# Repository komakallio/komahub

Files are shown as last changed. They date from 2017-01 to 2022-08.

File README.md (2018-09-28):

KomaHub Remote Power Switch and Sensor Platform
===============================================

Contents
--------

**EDA** - schematics and board layout, made in Eagle

**case** - STL files for a 3D-printed case

**software** - KomaHub control software

**firmware** - Firmware code

**tools** - tools for operating the KomaHub

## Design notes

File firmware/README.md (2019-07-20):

# KomaHub firmware

## Compiling the firmware

In order for the firmware to use a custom USB Product ID, the usb_rawhid core must be manually modified as there
is no way to do this from Arduino/PlatformIO code.

`~/.platformio/packages/framework-arduinoteensy/cores/usb_rawhid/usb_private.h`:

```
#define VENDOR_ID               0x1209
#define PRODUCT_ID              0x4242
```

```
#ifndef STR_PRODUCT
#define STR_PRODUCT             L"KomaHub Remote Power Switch"
#endif
#ifndef STR_RAWHID
#define STR_RAWHID              L"KomaHub Remote Power Switch"
#endif
```

Also add the following definition to let firmware code know that the core has been modified:

`~/.platformio/packages/framework-arduinoteensy/cores/usb_rawhid/core_id.h`:

```
#define CORE_KOMAHUB_OK
```

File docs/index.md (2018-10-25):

KomaHub is an intelligent power and sensor hub designed for astronomical applications. It’s particularly useful for running a remote control astrophotography setup. Typical use cases are:

- Troubleshoot a stuck device by power cycling
- Turn off a camera with no software fan control for daytime, for saving the fan
- Keep equipment powered on for preventing condensation
- Automatic dew heater control, following temperature and dewpoint
- Collect sensor data of sky quality during exposures

Manual available [in Finnish](manual-finnish.html)

Download control software from the [releases page](https://github.com/komakallio/komahub/releases).

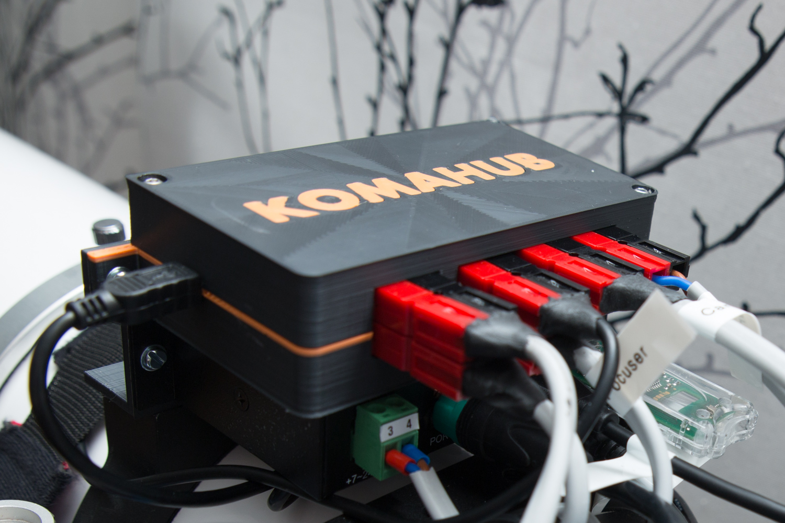
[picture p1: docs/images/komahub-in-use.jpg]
KomaHub in use


**Main features**:
- Six (6) intelligent switchable 12 V outputs
  - Maximum current 8 A per port, 15 A total
  - Chip level protection for overload, overtemperature, polarity and short circuit
  - Continuous current measurement on each port
  - Fast tripping soft fuse with user-definable current limit
- One always-on 12 V output, 15 A maximum
- Any output can use PWM to control dew heaters
  - Slow PWM frequency to prevent RF interference with camera
  - Outputs 1 and 2 can also use fast (xx khz) PWM for e.g. controlling fans (external filtering circuit may be required)
- Input voltage monitoring
- High-quality Anderson Powerpole connectors
- RJ45 port and two 3.5 mm stereo jacks for external sensors
  - Temperature + humidity + pressure sensor
  - 1-wire temperature sensors
  - Cloud sensor
  - Sky quality (darkness) sensor
- Atmel ATmega32U4 microcontroller
- Computer connection with USB HID - no need for serial port drivers
- Control software for Windows
- ASCOM ObservingConditions driver
- ASCOM SafetyMonitor driver for a clean shutdown if running on batteries
- Open firmware, communication protocol, drivers and software

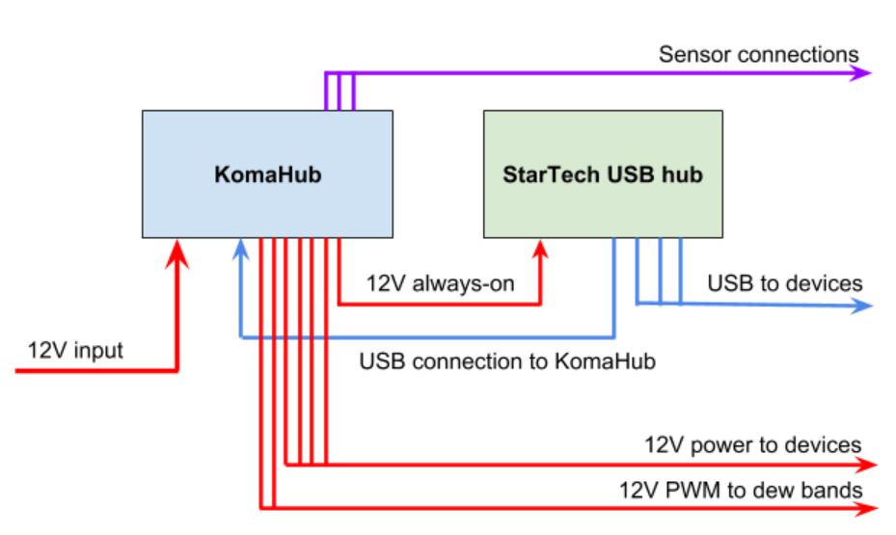
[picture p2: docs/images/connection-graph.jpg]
KomaHub connectivity


The KomaHub is designed to be used with StarTech industrial USB hubs that accept 12V input voltage and have proven to be very reliable. This way the always-on power output can be connected to the hub, making KomaHub always available to the computer. You can also chain KomaHubs together via the always-on port, but the total current level may not exceed 15 amperes.

## Power Switching

The main KomaHub feature is six computer-controlled 12V ports capable of delivering up to 8 A per channel or 15 A in total. The switching is implemented with latest Infineon PROFET switches, designed for rough environments such as automotive use. They feature the latest protection technologies along with high throughput and real-time current measurement.

The power to each port can be toggled from the provided control software. Each port provides either steady DC for your devices or PWM-modulated power for dew heaters. The rate of the PWM is deliberately kept very slow, in order to not disturb sensitive devices such as imaging cameras.

Each port has a software fuse with user-definable current limits. They are much faster than regular fuses and resettable from the control software. Ideal for remote use!

The 12V input voltage of the system is constantly monitored. An user-definable low voltage limit may be specified for shutting down power ports if your input voltage drops due to e.g. a low battery. The low voltage condition can be communicated to your imaging software via an ASCOM SafetyMonitor driver for a controlled shutdown.

## External Sensors

KomaHub can be used for collecting data of external sensors. There are three external connectors.

- The RJ45 connector houses ground and 5 volt lines, I2C bus lines (SCL, SDA) and SPI bus lines (MOSI, MISO, CLK, CS). 
- Usable I2C sensors include
  - *BME280 temperature/humidity/pressure sensor* - Measures ambient conditions for ASCOM or for automatic control of dew heaters
  - *MLX90614 infrared temperature sensor* - Measures sky temperature for sensing cloudiness. Narrow field of view version of the sensor can be aligned with th telescope.

One 3.5 mm stereo jack can be used for a chain of 1-wire temperature sensors (DS18B20), sensing dew heater temperature for automatic control.

The second 3.5 mm jack is used for sensing night sky quality with the TSL237 light-to-frequency sensor, same one as used in Unihedron Sky Quality Meter.

All sensor data can be relayed to the ASCOM ObservingConditions driver and be written in, e.g., the FITS header metadata.

The I2C and 1-wire lines have on-board pullup resistors which can be disabled using jumpers, if using sensor breakout boards with pullups installed.

The KomaHub firmware and software is open source for enabling the use of other sensors. Custom firmware also enables to use any of the available 8 data lines as general purpose I/O for other applications.

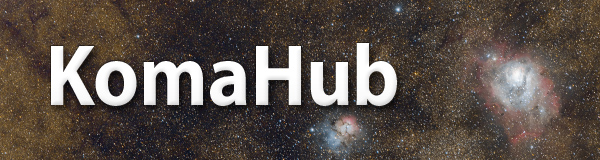
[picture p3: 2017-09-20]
software/KomaHub/KomaHub/Resources/komahub.jpg

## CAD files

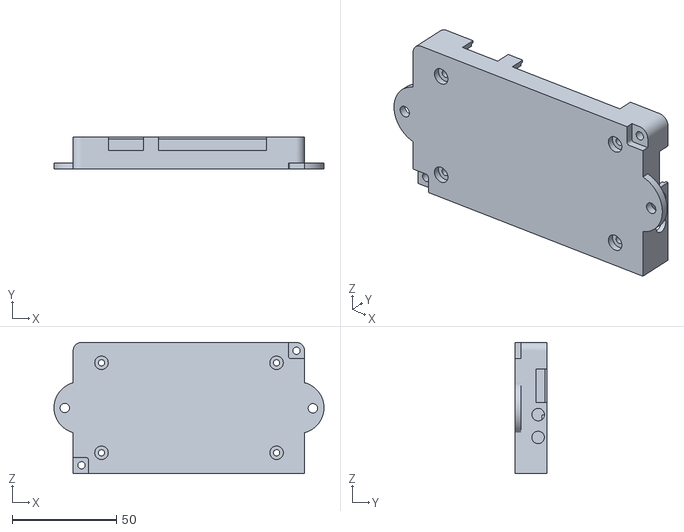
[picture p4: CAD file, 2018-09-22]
case/Komahub-1.2-BODY.stl
129.6 x 15.5 x 63.0

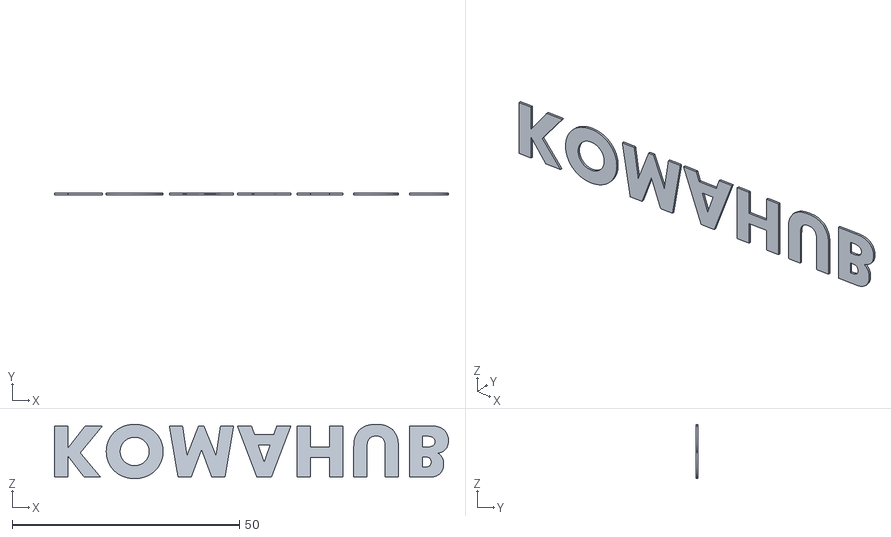
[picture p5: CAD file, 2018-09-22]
case/Komahub-1.2-LOGO.stl
86.7 x 0.45 x 11.9

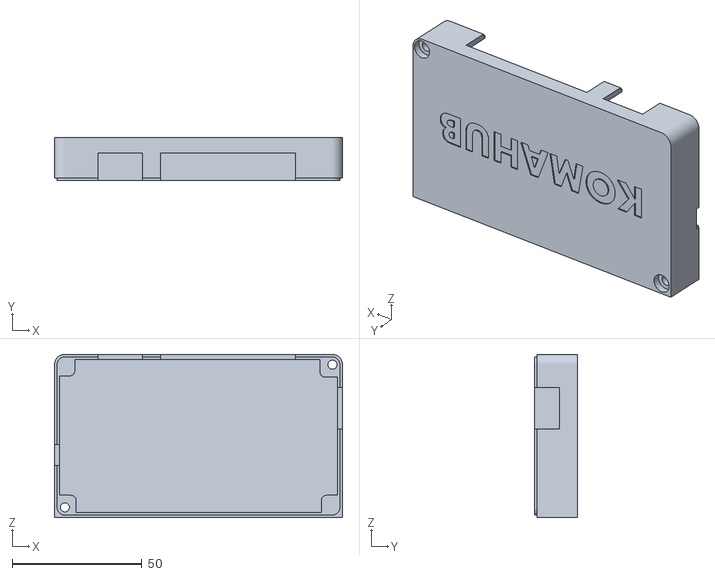
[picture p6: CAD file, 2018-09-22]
case/Komahub-1.2-LID.stl
111.0 x 16.5 x 63.0

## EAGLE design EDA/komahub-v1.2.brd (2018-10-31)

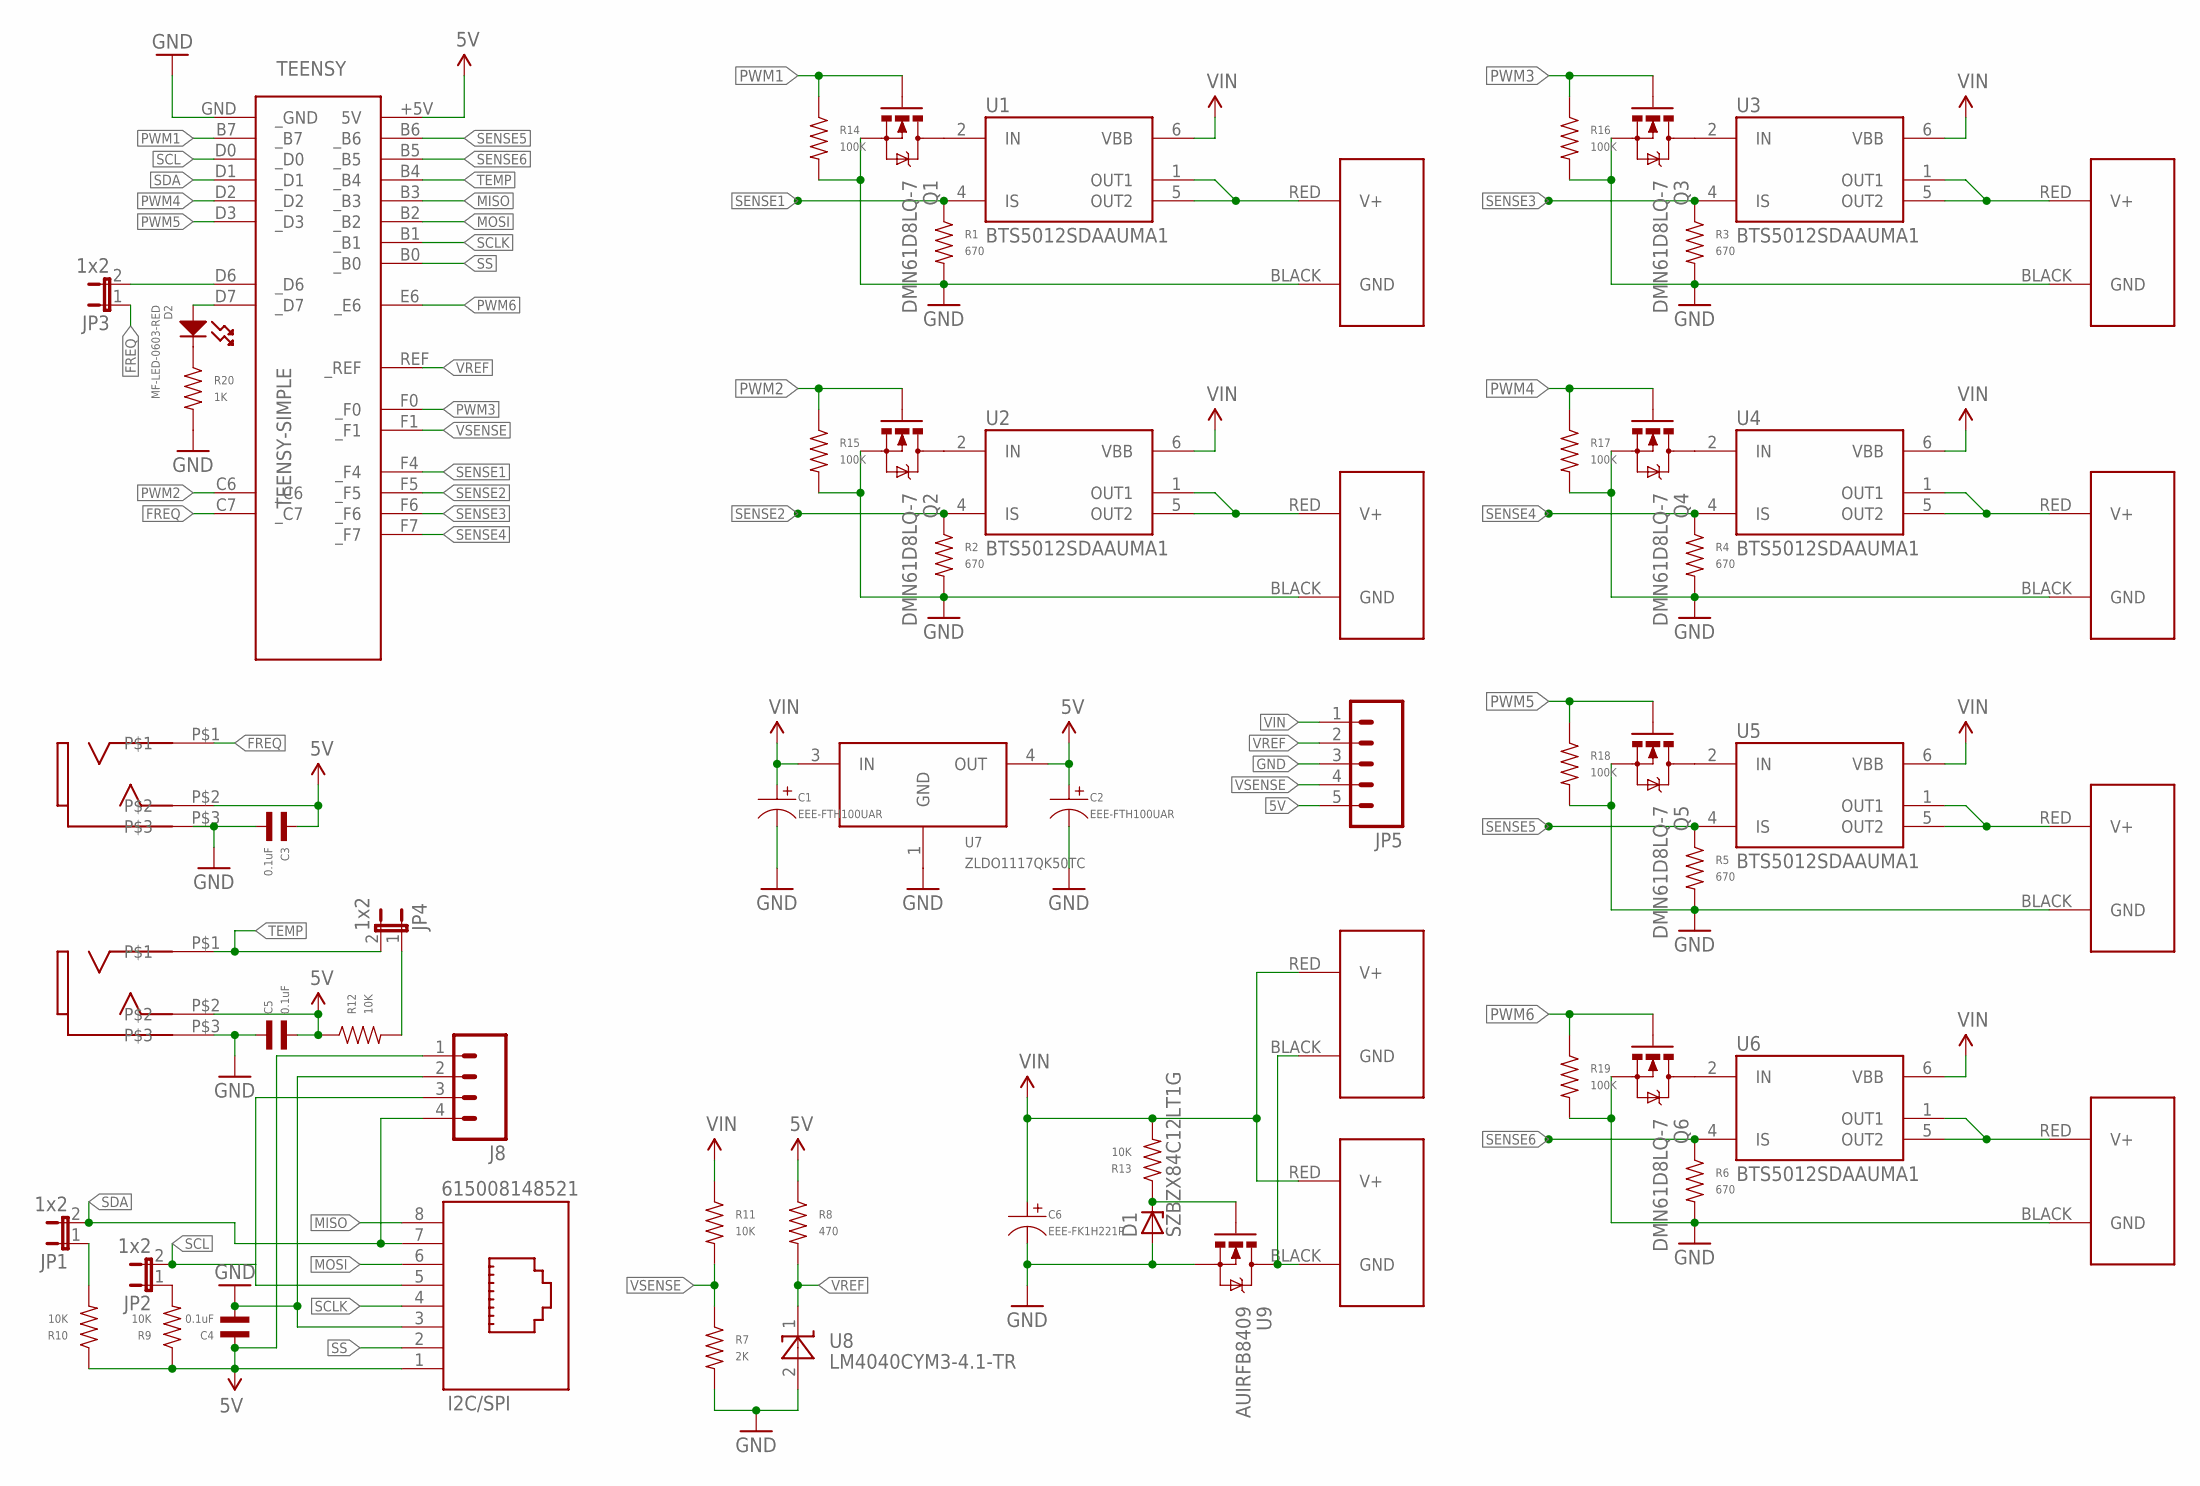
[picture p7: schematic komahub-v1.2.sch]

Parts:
C1, C2: EEE-FTH100UAR; CP4MM; MPN MF-CAP-4MM-10uF
C3, C4, C5: 0.1uF; C0603
C6: EEE-FK1H221P; CP10MM; MPN EEE-FT1H221AP
D1: SZBZX84C12LT1G; SOT23
D2: MF-LED-0603-RED; LED0603
FREQ: 35RASMT2BHNTRX
I2C/SPI: 615008148521
J1, J2, J6, J7: POWERPOLE_POWER25A_HORIZONTAL_G11; POWERPOLE_PAIR_25A_HORIZ_G11
J3, J4, J5, J9: POWERPOLE_POWER25A_HORIZONTAL_G12; POWERPOLE_PAIR_25A_HORIZ_G12
J8: M04PTH; 1X04
JP1, JP2, JP3, JP4: 1x2; 1X02
JP5: M05PTH; 1X05
Q1, Q2, Q3, Q4, Q5, Q6: DMN61D8LQ-7; SOT23-3
R1, R2, R3, R4, R5, R6: 670; R0603; MPN CR0603-FX-6800ELF
R7: 2K; R0603; MPN MF-RES-0603-2K
R8: 470; R0603; MPN MF-RES-0603-470
R9, R10, R11, R12, R13: 10K; R0603; MPN MF-RES-0603-10K
R14, R15, R16, R17, R18, R19: 100K; R0603; MPN MF-RES-0603-2K
R20: 1K; R0603
TEENSY: TEENSY-SIMPLE
TEMP: 35RASMT2BHNTRX
U1, U2, U3, U4, U5, U6: BTS5012SDAAUMA1; TO114P998X235-5_6N
U7: ZLDO1117QK50TC; DPAK
U8: LM4040CYM3-4.1-TR; SOT-23
U9: AUIRFB8409; TO220AV

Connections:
5V: C2.P$1, C3.P$1, C4.P$1, C5.P$2, FREQ.P$2, I2C/SPI.1 (8), J8.1, JP5.5, R8.P$1, R9.P$1, R10.P$1, R12.P$1, TEENSY.+5V (5V), TEMP.P$2, U7.4 (OUT)
FREQ: FREQ.P$1, JP3.1, TEENSY.C7 (_C7)
GND: C1.P$2, C2.P$2, C3.P$2, C4.P$2, C5.P$1, C6.P$2, D1.1 (A), FREQ.P$3, I2C/SPI.3 (6), J1.BLACK (GND), J2.BLACK (GND), J3.BLACK (GND), J5.BLACK (GND), J7.BLACK (GND), J8.2, J9.BLACK (GND), JP5.3, Q1.2 (S), Q2.2 (S), Q3.2 (S), Q4.2 (S), Q5.2 (S), Q6.2 (S), R1.P$2, R2.P$2, R3.P$2, R4.P$2, R5.P$2, R6.P$2, R7.P$2, R14.P$2, R15.P$2, R16.P$2, R17.P$2, R18.P$2, R19.P$2, R20.P$2, TEENSY.GND (_GND), TEMP.P$3, U7.1 (GND), U8.2 (A), U9.3 (S)
GNDIN: J4.BLACK (GND), J6.BLACK (GND), U9.2 (D)
MISO: I2C/SPI.8 (1), TEENSY.B3 (_B3)
MOSI: I2C/SPI.6 (3), TEENSY.B2 (_B2)
unnamed: JP3.2, TEENSY.D6 (_D6)
unnamed: JP2.1, R9.P$2
unnamed: JP4.1, R12.P$2
unnamed: JP1.1, R10.P$2
unnamed: D1.3 (C), R13.P$1, U9.1 (G)
unnamed: D2.CATHODE, R20.P$1
unnamed: D2.ANODE, TEENSY.D7 (_D7)
PWM1: Q1.1 (G), R14.P$1, TEENSY.B7 (_B7)
PWM2: Q2.1 (G), R15.P$1, TEENSY.C6 (_C6)
PWM3: Q3.1 (G), R16.P$1, TEENSY.F0 (_F0)
PWM4: Q4.1 (G), R17.P$1, TEENSY.D2 (_D2)
PWM5: Q5.1 (G), R18.P$1, TEENSY.D3 (_D3)
PWM6: Q6.1 (G), R19.P$1, TEENSY.E6 (_E6)
PWMT1: Q1.3 (D), U1.2 (IN)
PWMT2: Q2.3 (D), U2.2 (IN)
PWMT3: Q3.3 (D), U3.2 (IN)
PWMT4: Q4.3 (D), U4.2 (IN)
PWMT5: Q5.3 (D), U5.2 (IN)
PWMT6: Q6.3 (D), U6.2 (IN)
PWR1: J2.RED (V+), U1.1 (OUT1), U1.5 (OUT2)
PWR2: J3.RED (V+), U2.1 (OUT1), U2.5 (OUT2)
PWR3: J1.RED (V+), U3.1 (OUT1), U3.5 (OUT2)
PWR4: J5.RED (V+), U4.1 (OUT1), U4.5 (OUT2)
PWR5: J7.RED (V+), U5.1 (OUT1), U5.5 (OUT2)
PWR6: J9.RED (V+), U6.1 (OUT1), U6.5 (OUT2)
SCL: I2C/SPI.5 (4), J8.3, JP2.2, TEENSY.D0 (_D0)
SCLK: I2C/SPI.4 (5), TEENSY.B1 (_B1)
SDA: I2C/SPI.7 (2), J8.4, JP1.2, TEENSY.D1 (_D1)
SENSE1: R1.P$1, TEENSY.F4 (_F4), U1.4 (IS)
SENSE2: R2.P$1, TEENSY.F5 (_F5), U2.4 (IS)
SENSE3: R3.P$1, TEENSY.F6 (_F6), U3.4 (IS)
SENSE4: R4.P$1, TEENSY.F7 (_F7), U4.4 (IS)
SENSE5: R5.P$1, TEENSY.B6 (_B6), U5.4 (IS)
SENSE6: R6.P$1, TEENSY.B5 (_B5), U6.4 (IS)
SS: I2C/SPI.2 (7), TEENSY.B0 (_B0)
TEMP: JP4.2, TEENSY.B4 (_B4), TEMP.P$1
VIN: C1.P$1, C6.P$1, J4.RED (V+), J6.RED (V+), JP5.1, R11.P$1, R13.P$2, U1.6 (VBB), U2.6 (VBB), U3.6 (VBB), U4.6 (VBB), U5.6 (VBB), U6.6 (VBB), U7.3 (IN)
VREF: JP5.2, R8.P$2, TEENSY.REF (_REF), U8.1 (C)
VSENSE: JP5.4, R7.P$1, R11.P$2, TEENSY.F1 (_F1)

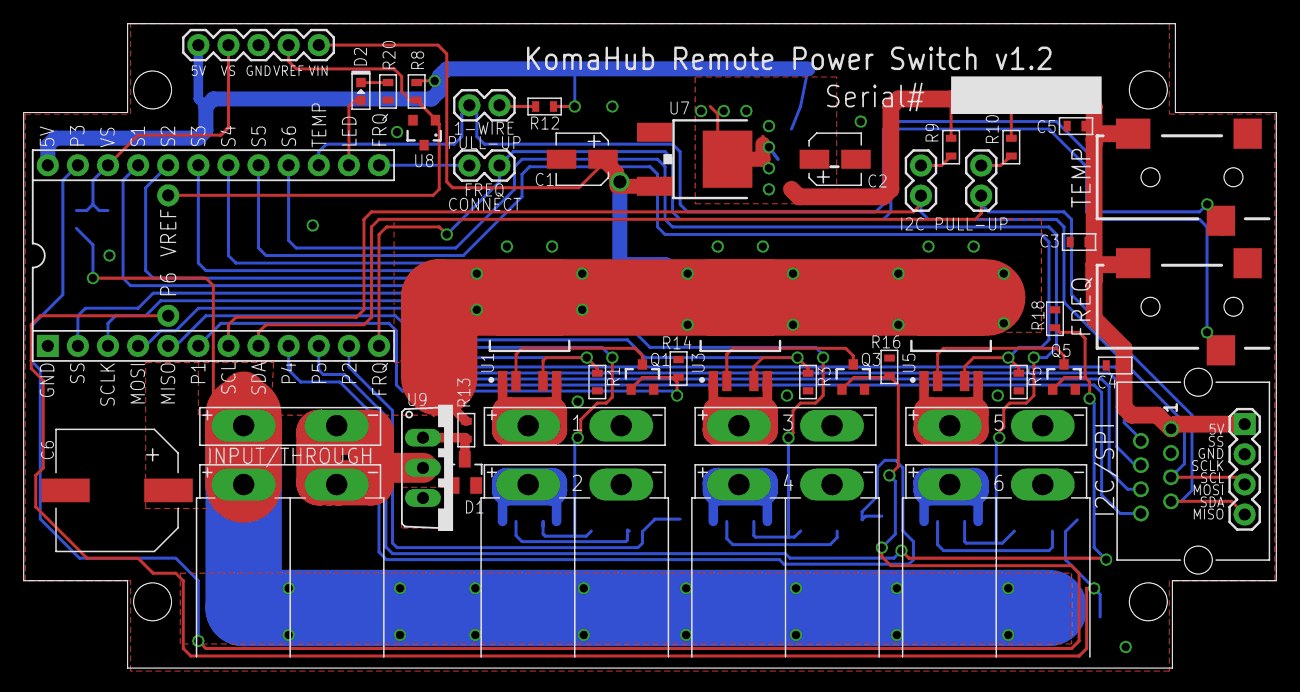
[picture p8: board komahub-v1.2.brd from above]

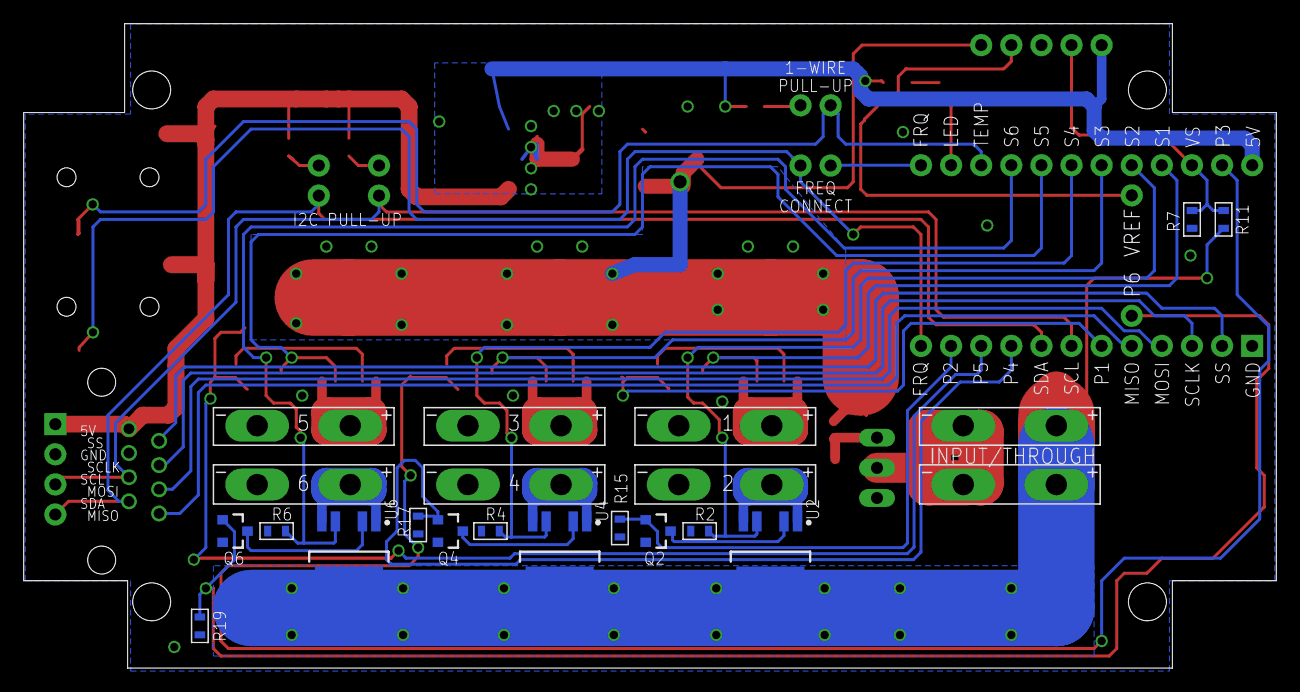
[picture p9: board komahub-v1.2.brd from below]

Board: 2 copper layers, 105.7 x 54.4 mm, 61 parts (14 on the bottom side), 45 nets.

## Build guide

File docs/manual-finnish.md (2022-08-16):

# KomaHub - kotimainen sähkölaatikko tähtikuvaukseen

KomaHub on Komakalliolla kehitetty apulaite tähtikuvaukseen. KomaHubilla korvaat perinteisen rinnankytketyn 12 voltin sähkönjakolaatikon ja saat hienoja lisäominaisuuksia.

Laite on erityisen hyödyllinen etäkäyttöisessä observatoriossa, jossa on tarve käynnistää ja sammuttaa 12 voltilla toimivia laitteita etänä ja tarkkailla niiden virrankulutusta. Lisäksi KomaHubiin on mahdollista kytkeä useita erilaisia antureita, joiden avulla voi tarkkailla kuvausolosuhteita ja tallentaa tämän tiedon suoraan raakakuvien metadataksi.

Tyypillisiä käyttökohteita ovat esimerkiksi:
- Temppuilevan laitteen korjaaminen katkaisemalla virrat
- CCD-kameran sammuttaminen päiväsajaksi, jos kameran tuuletin muuten pyörisi aina kun virta on kytkettynä
- Laitteiden pitäminen virroissa tiivistyvän kosteuden välttämiseksi
- Huurrepantojen automaattinen säätö kuvauksen aikana
- Taivaan pimeyden ja muiden suureiden mittaaminen kuvatessa

Ominaisuudet:
- Kuusi yksittäin tietokoneella ohjattavaa virtaulostuloa
  - Maksimi 8 A per portti, yhteensä 15 A
  - Jatkuva virtamittaus per portti
  - Ohjelmallisesti toteutettu nopea sulake käyttäjän valitsemalla virtarajoituksella
- Yksi jatkuvasti päällä oleva virtaulostulo (kytketty rinnan sisääntulon kanssa)
- Jokaiseen kuudesta ulostulosta voi määrittää PWM:n esim. huurrepannan ohjaamista varten
- Sisääntulojännitteen mittaus
- Laadukkaat Powerpole-liittimet
- Mahdollisuus kytkeä ulkoisia antureita (lämpötila, paine, kosteus, pilvisyys, taustataivaan kirkkaus)
- Atmel ATmega32U4 mikrokontrolleri
- Toimii USB HID-laitteena - ei sarjaporttiajureiden asentelua!
- Ohjausohjelma Windowsille
- ASCOM-ajurit ObservingConditions ja SafetyMonitor -rajapinnoille
- Kaikki lähdekoodi (firmware, protokollat, ajurit ja ohjelmisto) ja piirilevysuunnittelu on avoimesti jaossa

## Kytkennät

KomaHub kytketään tietokoneeseen Mini-USB-liittimellä. Lisäksi laitteelle syötetään 12 voltin käyttöjännite alla olevaan kuvaan merkityn Powerpole-liittimen kautta (**12V input**). Syöttöjännitteelle tarkoitetun liittimen alapuolella on toinen Powerpole-liitin, joka on kytketty rinnakkain syöttöjännitteen kanssa. Tästä liittimestä voi jakaa 12 V sähkön laitteille, joiden haluat aina olevan päällä, esim. USB-hubi, johon KomaHub on kytketty.

12 V syötön tulee olla aina kytkettynä. KomaHub osaa toimia itsenäisesti ilman tietokonetta pitäen voimassa sille määritellyt asetukset, joten se ei ota sähköä USB:n kautta eikä näin toimi ilman sähkönsyöttöä.

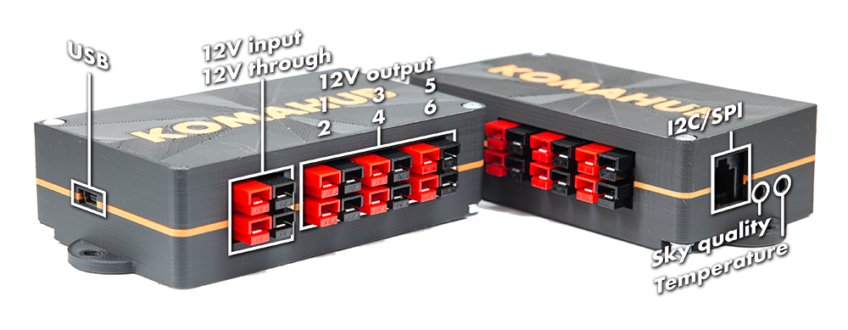
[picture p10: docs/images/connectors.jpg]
Liittimet


Kuvaan merkityt **12V output** -liittimet ovat KomaHubilla ohjattavia laitteita varten. Liittimet on numeroitu kuvassa näkyvässä järjestyksessä.

Lisäksi laitteen kyljessä ovat RJ45- ja 3,5 mm stereoliittimet erilaisia oheisantureita varten. Reunimmainen 3,5mm liitin on lämpötilasensoreita varten (**Temperature**), keskimmäinen 3,5mm liitin TSL237-valoisuusanturia varten (**Sky quality**) ja RJ45-liitin I2C/SPI -väyliin liitettäviä antureita varten (**I2C/SPI**), esim. lämpötila/ilmanpaine/kosteus (BME280) tai pilvisensori (MLX90614). Kun anturit eivät ole käytössä, voi kotelon kyljen teipata umpeen, jotta sisälle ei mene ulkokäytössä kosteutta tai ötököitä.

## Windows-ohjelman käyttö

KomaHubia ohjataan Windows-työpöytäohjelmalla, jonka käyttöliittymästä näet kuvakaappauksen alla. **Power Outputs** -otsikon alta näet listauksen kaikista kuudesta virtalähdöstä sekä niiden tilasta. Jokaiselle lähdölle voi antaa nimen, joka vastaa lähtöön kytkettyä laitetta. Käyttöliittymä näyttää myös jokaisen lähdön virrankulutuksen, sekä antaa mahdollisuuden kytkeä kukin lähtö päälle tai pois klikkaamalla **On/Off**-nappia.

Jos lähdön tyypiksi on asetuksissa valittu PWM, näkyy lähdölle myös käyttöjakson säätö (0-100%). Tällä voi esimerkiksi lämmityspantojen tapauksessa säätää lämmitystehoa.

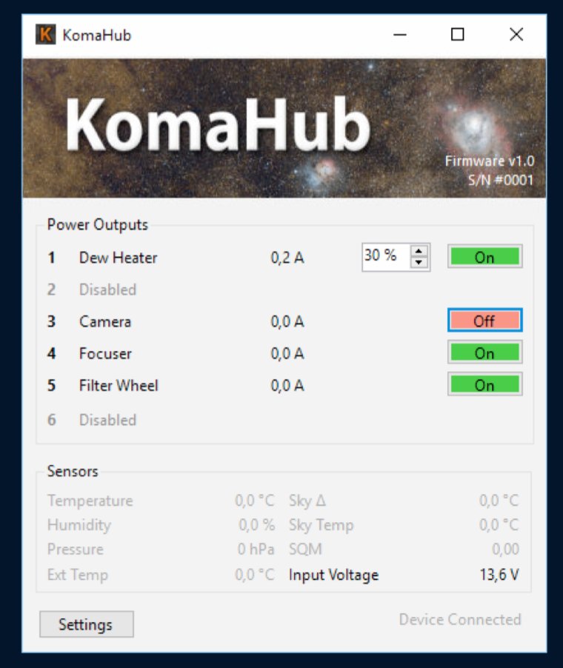
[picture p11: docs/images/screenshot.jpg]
KomaHub-kuvakaappaus


**Sensors**-otsikon alta näet kaikkien KomaHubiin kytkettyjen anturien tilan. Listan lopusta löytyy myös mitattu syöttöjännite. Syötetyn jännitteen tulisi olla välillä 12-14 V.

**Settings**-nappia painamalla voit säätää KomaHubin käyttämiä asetuksia. Jokaiselle lähdölle voi valita nimen, tyypin sekä sulakkeen käyttämän virtarajan.

Lähtöjen tyypit ovat seuraavanlaiset:
- **12V** - Lähtö on normaalisti käytössä ja antaa 12 voltin jännitettä
- **PWM** - Lähtö antaa säädettävää PWM-jännitettä, jolla voi ohjata esimerkiksi lämmityspantoja
- **OFF** - Lähdön käyttö on kokonaan estetty ja näkyy käyttöliittymässä *Disabled*-tilassa

## Linux-tuki

Jarno Paananen on tehnyt KomaHubille INDI-ajurin, joka löytyy osoitteesta https://github.com/jpaana/indi-komahub.

## Sensorikytkennät

KomaHubiin voidaan liittää monenlaisia sensoreita. Laite havaitsee kytketyt sensorit kun siihen kytketään virta, ja välittää niillä mitatut tiedot tietokoneelle, jossa niitä voi seurata KomaHubin ohjaussovelluksella.

**Huom!** Älä kytke tai irroita sensoreita kun KomaHubissa on virrat!

### One-wire lämpötila-anturit

KomaHubiin voidaan kytkeä ketjuun 1-4kpl DS18B20 lämpötila-anturia. Anturit johdotetaan 3,5mm TRS-stereoplugiin seuraavasti:

- Tip = +5V
- Ring = Data
- Sleeve = GND

Lisäksi tarvitaan ylösvetovastus Data- ja +5V-linjojen väliin. Jos anturisi yhteydessä ei sellaista ole, voi KomaHubin sisäänrakennetun vastuksen kytkeä käyttöön sulkemalla piirilevyltä jumpperi `1-WIRE PULL-UP`.

KomaHub tunnistaa antureiden lukumäärän käynnistyessään. Mittaus tehdään neljälle anturille, joista KomaHubin ohjaussovellus näyttää kaksi ensimmäistä.

### TSL237 valoisuusanturi

TSL237-valoisuusanturilla voidaan mitata taivaan kirkkautta. Lopputuloksena saadaan vastaava magnitudia/neliökaarisekunti-tulos kuin Unihedronin valmistamilla SQM-mittareilla. Vertailukelpoisen tuloksen saamiseksi anturi tarvitsee eteensä IR:n ja UV:n leikkaavan suodattimen (Unihedronin laitteessa HOYA CM-500) sekä linssin jolla mittaukseen haluttu kuvakenttä kohdistetaan anturiin.

Itse anturi muuttaa kirkkauden taajuuspulssiksi jota KomaHubin mikrokontrolleri lukee. Taajuus `f` muunnetaan mag/arcsec^2 -lukemaksi kaavalla `22 - 2.5 * log10(f)`. Mitattu taajuuslukema on myös saatavilla omia laskelmia varten ohjaussovelluksessa tooltippinä osoittamalla hiirellä Sky Quality -lukemaa. Koska anturilta saatavan taajuuden vaihteluväli on erittäin suuri (n. 0,1Hz - 500kHz), käyttää KomaHub sen seuraamiseen kahta eri mekanismia jotta saadaan paras tarkkuus mahdollisimman vähällä CPU-kuormalla. Anturin ollessa käytössä on piirilevyltä suljettava `FREQ CONNECT` -jumpperi, jotta signaali saadaan jaettua mikrokontrollerille kahteen eri pinniin eri lukumekanismien mahdollistamiseksi.

Laite johdotetaan 3,5mm TRS-stereoplugiin seuraavasti:

- Tip = Vdd (2)
- Ring = OUT (3)
- Sleeve = GND (1)

Lisäksi laitteen lähelle Vdd ja GND -linjojen väliin tulee liittää 0.1uF kondensaattori.

**Huom!** Valoisuusanturin tuloksia ei ole vielä päästy vertaamaan ja kalibroimaan oikean SQM-mittarin kanssa. Käyttäjäkokemuksia otetaan vastaan!

### BME280 lämpötila/ilmanpaine/kosteus

BME280 on Boschin valmistama edullinen yhdistelmäanturi, josta saadaan kerralla paikallinen lämpötila, ilmanpaine, kosteus ja näistä edelleen laskettua kastepiste. Anturia saa valmiina I2C breakout-lautana, joka johdotetaan KomaHubin RJ45-liittimeen seuraavasti:

- 1 = +5V
- 3 = GND
- 5 = SCL
- 7 = SDA

Valmiissa breakout-laudoissa on yleensä I2C-väylän tarvitsemat ylösvetovastukset valmiina. Omia rakennelmia tai laitteiden ketjuttamista varten KomaHubissa on myös omat ylösvetovastukset jotka saa käyttöön sulkemalla KomaHubin piirilevyltä kaksi `I2C PULL-UP` -jumpperia.

### MLX90614-sensori pilvisyyden mittaamiseen

MLX90614 on komponentti, joka mittaa kohteesta saapuvan lämpösäteilyn määrää.  Lisäksi siinä on oma lämpötilamittarinsa paikallista referenssilämpötilaa varten. Tällä yhdistelmällä voidaan mitata taivaan pilvisyyttä mittaamalla taivaan ja ilman lämpötilan erotusta. Selkeä taivas on kylmempi kuin pilvinen, joten erotuksen ollessa suuri on keli todennäköisesti selkeä.

Laitetta saa valmiina breakout-lautana, joka liitetään I2C-väylään samalla tavalla kuin BME280:

- 1 = +5V
- 3 = GND
- 5 = SCL
- 7 = SDA

Lisäksi KomaHubin piirilevyltä on suljettava `I2C PULL-UP` -jumpperit, jos sensorin yhteydessä ei ole omia ylösvetovastuksia.

### Muut sensorit

RJ45-liittimeen voidaan kytkeä myös muita I2C- tai SPI-väyliin liitettäviä laitteita. Näille täytyy kuitenkin toteuttaa tuki KomaHubin firmwareen tapauskohtaisesti. Liittimen kytkennät ovat:

- 1 = +5V
- 2 = SS
- 3 = GND
- 4 = SCLK
- 5 = SCL
- 6 = MOSI
- 7 = SDA
- 8 = MISO

## Komentoriviohjaus

KomaHubin Windows-sovelluksessa on REST-verkkorajapinta, jolla laitetta on mahdollista ohjata omista sovelluksista käsin. KomaHubin ASCOM-ajurit käyttävät myös näitä rajapintoja. Komentorivillä näitä voidaan ohjata esim. `curl`-työkalulla.

### Lähtöjen kytkentä päälle/pois

`curl -X POST -d '' http://localhost:6563/output/1/on`  
`curl -X POST -d '' http://localhost:6563/output/1/off`

jossa `output` on lähdön numero 1-6.

### Sensorien lukeminen

`curl http://localhost:6563/sensors`

Tämä kutsu tuottaa seuraavanlaisen JSON-dokumentin joka sisältää sensoreilta viimeksi luetut arvot. Jos vastaavaa sensoria ei ole kytketty, kyseinen osio tai lukema jää vastauksesta kokonaan pois. `power`-osio on kuitenkin aina mukana, sillä se on KomaHubiin sisäänrakennettuna.
```
{
  "pth" : { "temperature": 3.5, "humidity": 70.5, "pressure": 1001.5, "dewpoint": -3.2 },
  "skyquality" : { "magnitude": 21.3, "frequency": 1005 },
  "skytemperature" : { "sky": -15.3, "ambient": 0.2 },
  "power" : { "inputvoltage": 12.5, "outputcurrent": [ 0.0, 0.0, 0.0, 0.0, 0.0, 0.0 ] },
  "temperatures": [ 10.5, 9.5 ]
}
```

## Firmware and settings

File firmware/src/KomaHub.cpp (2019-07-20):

/*
 * Copyright (c) 2016 Jari Saukkonen
 *
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
 * THE SOFTWARE IS PROVIDED "AS IS", WITHOUT WARRANTY OF ANY KIND,
 * EXPRESS OR IMPLIED, INCLUDING BUT NOT LIMITED TO THE WARRANTIES OF
 * MERCHANTABILITY, FITNESS FOR A PARTICULAR PURPOSE AND NONINFRINGEMENT.
 * IN NO EVENT SHALL THE AUTHORS OR COPYRIGHT HOLDERS BE LIABLE FOR ANY
 * CLAIM, DAMAGES OR OTHER LIABILITY, WHETHER IN AN ACTION OF CONTRACT,
 * TORT OR OTHERWISE, ARISING FROM, OUT OF OR IN CONNECTION WITH THE
 * SOFTWARE OR THE USE OR OTHER DEALINGS IN THE SOFTWARE.
 */

#include <Arduino.h>
#include <TaskScheduler.h>
#ifdef CORE_TEENSY_SERIAL
#include <EEPROM.h>
#elif defined(CORE_TEENSY_RAWHID) && !defined(CORE_KOMAHUB_OK)
#error "KomaHub custom core (with proper USB vendor/product ids) not found!"
#elif !defined(CORE_TEENSY_RAWHID)
#error "Teensy core (serial/raw hid) not selected!"
#endif

#include "AnalogInput.h"
#include "HubConfiguration.h"
#include "PowerOutputs.h"
#include "SkyQuality.h"
#include "SkyTemperature.h"
#include "TemperatureSensors.h"
#include "USB.h"
#include "Weather.h"
#include "VersionSpecifics.h"
#include "VoltageMonitor.h"

static Scheduler taskScheduler;
static HubConfiguration configuration;
#ifdef CORE_TEENSY_RAWHID
static Task usbTask(10, TASK_FOREVER, &USB::loop);
#endif
static Task skyQualityTask(50, TASK_FOREVER, &SkyQuality::loop);
static Task skyTemperatureTask(1000, TASK_FOREVER, &SkyTemperature::loop);
static Task analogInputTask(10, TASK_FOREVER, &AnalogInput::loop);
static Task powerOutputsTask(5, TASK_FOREVER, &PowerOutputs::loop);
static Task temperatureSensorsTask(2000, TASK_FOREVER, &TemperatureSensors::loop);
static Task weatherTask(2000, TASK_FOREVER, &Weather::loop);
static Task voltageMonitorTask(10, TASK_FOREVER, &VoltageMonitor::loop);

void setup() {
    configuration.loadStoredConfiguration();
    VersionSpecifics::setBoardRevision(configuration.getFactoryConfig().boardRevision);

    taskScheduler.init();
#ifdef CORE_TEENSY_RAWHID
    USB::init(&configuration);
    taskScheduler.addTask(usbTask);
#endif

    AnalogInput::init(&configuration);
    taskScheduler.addTask(analogInputTask);

    PowerOutputs::init(&configuration);
    taskScheduler.addTask(powerOutputsTask);

    VoltageMonitor::init(&configuration);
    taskScheduler.addTask(voltageMonitorTask);

    SkyQuality::init(&configuration);
    taskScheduler.addTask(skyQualityTask);

    SkyTemperature::init(&configuration);
    taskScheduler.addTask(skyTemperatureTask);

    TemperatureSensors::init(&configuration);
    taskScheduler.addTask(temperatureSensorsTask);

    Weather::init(&configuration);
    taskScheduler.addTask(weatherTask);

    taskScheduler.enableAll();
}

void loop() {
    taskScheduler.execute();
#ifdef CORE_TEENSY_SERIAL
    if (Serial.available()) {
        char ch = Serial.read();
        if (ch == 'd') {
            Serial.print("eeprom dump: ");
            for (int i = 0; i < 1024; i++) {
                if (i % 32 == 0) Serial.println();
                Serial.print(EEPROM.read(i), HEX);
                Serial.print(" ");
            };
            Serial.println();
        }
        if (ch == 'f') {
            configuration.factoryReset(1, 6, 12000, 2000, 255, 220, 15);
            Serial.println("factory was reset");
        }
    }
#endif
}

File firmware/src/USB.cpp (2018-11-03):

/*
 * Copyright (c) 2016 Jari Saukkonen
 *
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
 * THE SOFTWARE IS PROVIDED "AS IS", WITHOUT WARRANTY OF ANY KIND,
 * EXPRESS OR IMPLIED, INCLUDING BUT NOT LIMITED TO THE WARRANTIES OF
 * MERCHANTABILITY, FITNESS FOR A PARTICULAR PURPOSE AND NONINFRINGEMENT.
 * IN NO EVENT SHALL THE AUTHORS OR COPYRIGHT HOLDERS BE LIABLE FOR ANY
 * CLAIM, DAMAGES OR OTHER LIABILITY, WHETHER IN AN ACTION OF CONTRACT,
 * TORT OR OTHERWISE, ARISING FROM, OUT OF OR IN CONNECTION WITH THE
 * SOFTWARE OR THE USE OR OTHER DEALINGS IN THE SOFTWARE.
 */

#include <Arduino.h>

#ifdef CORE_TEENSY_RAWHID

#include "AnalogInput.h"
#include "HubConfiguration.h"
#include "PowerOutputs.h"
#include "SkyQuality.h"
#include "SkyTemperature.h"
#include "TemperatureSensors.h"
#include "USB.h"
#include "USBCommands.h"
#include "Weather.h"
#include "Version.h"
#include "VoltageMonitor.h"

static uint8_t usbSendBuffer[64];
static uint8_t usbRecvBuffer[64];

HubConfiguration* USB::hubConfiguration;

void USB::loop() {
    int available = RawHID.available();
    if (available > 0) {
        memset(usbSendBuffer, 0, 64);
        RawHID.recv(usbRecvBuffer, available);
        handleCommands(usbRecvBuffer, available);
    }
}

void USB::handleCommands(uint8_t* data, unsigned int maxlen) {
    unsigned int pos = 0;
    if (data[pos++] != 'K')
        return;

    while (pos < maxlen) {
        uint8_t command = data[pos++];
        switch (command) {
            case END: {
                return;
            }

            case GETFACTORYSETTINGS: {
                const HubConfiguration::FactoryConfig& factoryConfig = hubConfiguration->getFactoryConfig();
                GetFactorySettingsResponse response;

                response.firmwareVersion = (KOMAHUB_FIRMWARE_VERSION_MAJOR << 8) + KOMAHUB_FIRMWARE_VERSION_MINOR;
                response.serialNumber = factoryConfig.serial;
                response.fuseDelay = factoryConfig.fuseDelay;
                response.skyQualityOffset = factoryConfig.skyQualityOffset;
                response.features = (uint8_t)(
                    (factoryConfig.features.tempprobes ? (1 << 0) : 0) +
                    (factoryConfig.features.skyquality ? (1 << 1) : 0) +
                    (factoryConfig.features.ambientpth ? (1 << 2) : 0) +
                    (factoryConfig.features.skytemp ? (1 << 3) : 0));
                response.boardRevision = factoryConfig.boardRevision;

                memcpy(usbSendBuffer, &response, sizeof(GetFactorySettingsResponse));
                RawHID.send(usbSendBuffer, 1000);
                break;
            }

            case GETOUTPUTSETTINGS: {
                GetOutputSettingsCommand* cmd = (GetOutputSettingsCommand*)&data[pos];
                if (!isValidOutput(cmd->outputNumber))
                    break;
                GetOutputSettingsResponse response;

                const HubConfiguration::OutputSettings& outputSettings = hubConfiguration->getOutputSettings();
                const HubConfiguration::Output& output = outputSettings.outputs[cmd->outputNumber];
                memcpy(&response.name, output.name, 16);
                response.fuseCurrent = output.fuseCurrent;
                response.type = output.type.type;

                memcpy(usbSendBuffer, &response, sizeof(GetOutputSettingsResponse));
                RawHID.send(usbSendBuffer, 1000);
                pos += sizeof(GetOutputSettingsCommand);
                break;
            }

            case GETSTATUS: {
                GetStatusResponse response;

                const HubConfiguration::State& state = hubConfiguration->getState();
                response.relayIsOpenBits = state.relayIsOpenBits;
                response.fuseIsBlownBits = state.fuseIsBlownBits;
                for (int i = 0; i < 6; i++) {
                    response.pwmPercentages[i] = state.pwmPercentages[i];
                }
                // input voltage
                response.inputVoltage = (uint8_t)roundf(VoltageMonitor::getInputVoltage() * 10);
                // output power, amps
                for (int i = 0; i < 6; i++) {
                    response.outputPower[i] = (uint8_t)roundf(PowerOutputs::getOutputPower(i) * 10);
                }
                // 1-wire temperature probes
                response.numberOfTemperatureProbes = TemperatureSensors::getNumberOfSensors();
                for (int i = 0; i < 4; i++) {
                    response.temperatureProbes[i] = TemperatureSensors::getCurrentTemperatureValues()[i] * 10;
                }
                // weather
                response.pthpresent = Weather::isSensorPresent();
                response.temperature = Weather::getTemperature() * 10;
                response.humidity = Weather::getHumidity();
                response.pressure = Weather::getPressure() * 10;
                response.dewpoint = Weather::getDewPoint() * 10;
                // sky quality
                response.skyqualitypresent = SkyQuality::isSensorPresent();
                response.skyquality = SkyQuality::getSkyQuality() * 10;
                response.skyqualityfreq = SkyQuality::getFrequencyHz() * 10;
                // sky temperature
                response.skytemperaturepresent = SkyTemperature::isSensorPresent();
                response.skytemperature = SkyTemperature::getSkyTemperature() * 10;
                response.skyambienttemperature = SkyTemperature::getAmbientTemperature() * 10;

                memcpy(usbSendBuffer, &response, sizeof(GetStatusResponse));
                RawHID.send(usbSendBuffer, 1000);
                break;
            }

            case GETRAWPOWERUSAGE: {
                GetRawPowerUsageResponse response;
                memcpy(&response.rawValues, AnalogInput::getAverageValues(), 8*sizeof(uint16_t));
                memcpy(usbSendBuffer, &response, sizeof(GetRawPowerUsageResponse));
                RawHID.send(usbSendBuffer, 1000);
                break;
            }

            case FACTORYRESET: {
                FactoryResetCommand* cmd = (FactoryResetCommand*)&data[pos];
                USB::hubConfiguration->factoryReset(cmd->serial, cmd->r6ohms, cmd->r7ohms, cmd->boardRevision);
                pos += sizeof(FactoryResetCommand);
                break;
            }

            case REBOOT_BOOTLOADER: {
                cli();
                // disable watchdog, if enabled
                // disable all peripherals
                UDCON = 1;
                UCSR1B = 0;
                delay(5);
                EIMSK = 0; PCICR = 0; SPCR = 0; ACSR = 0; EECR = 0; ADCSRA = 0;
                TIMSK0 = 0; TIMSK1 = 0; TIMSK3 = 0; TIMSK4 = 0; UCSR1B = 0; TWCR = 0;
                DDRB = 0; DDRC = 0; DDRD = 0; DDRE = 0; DDRF = 0; TWCR = 0;
                PORTB = 0; PORTC = 0; PORTD = 0; PORTE = 0; PORTF = 0;
                asm volatile("jmp 0x7000");
                break;
            }
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

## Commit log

2017-01-25 Initial revision
    [komahub-v1.0.brd, komahub-v1.0.sch]
2017-01-25 Fix multiple commands in one packet
    [USB.cpp]
2017-02-11 Avoid error message for commands that do not send responses
    [hidsend.py]
2017-02-11 Initial implementation for reading voltage and sense current
2017-02-12 Fix interrupt-driven ADC sampling
    [AnalogInput.cpp, HubConfiguration.h, KomaHub.ino]
2017-02-12 Remove LED debugging code
2017-02-15 Implement fuse handling, fix eeprom handling to persist state, add serial debug mode
    [AnalogInput.cpp, HubConfiguration.h, KomaHub.ino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]
2017-02-15 Fix reading the serial number
    [status.py]
2017-09-20 Update tools to work with current komahub
2017-09-28 Use table layout in main form; more communication with device
2017-09-30 Make things (UI sync with hardware, PWM, etc) work
2017-09-30 Simplify command protocol by removing command length. Fix bugs in GetOutputCommand and struct padding
    [HubConfiguration.h, USB.cpp]
2017-10-02 Pack EEPROM data structures tightly
    [HubConfiguration.h]
2017-10-02 Add commands for updating some factory configuration data and rebooting to bootloader for firmware updates
    [USB.cpp]
2017-10-03 Reorganize power output / input voltage parsing; get rid of ringbuffer in AnalogInput and calculate average values in sync relative to the pwm cycle
2017-10-03 Implement fuse reset
2017-10-03 Initialize fuse delay and sky quality default value
2017-10-07 First shot at measuring power output calibration data
2017-10-09 Measure and produce output calibration data; does not yet upload calibration coefficients to komahub
2017-10-10 Raise error if calibration coefficients are out of range
    [powercalibration.py]
2017-10-10 Better approximation of true power output using a second-order function and external calibration
2017-10-10 Send power output calibration data to KomaHub
2017-10-11 Use real calibration coefficients in factory reset
2017-10-11 Fix overflow in initialization
    [AnalogInput.cpp]
2017-10-11 Add get power usage -command
2017-10-11 Fix rebooting to bootloader
    [USB.cpp]
2017-10-11 Fix power output and input voltage calculations
    [PowerOutputs.cpp, USB.cpp]
2017-10-13 Store board revision to EEPROM so that we are able to support multiple board revisions with the same firmware code
2017-10-13 Support slower than instant fuses; collect power usage data into a cyclical history buffer to be able to slow down fuse tripping
2017-10-14 Skeleton code for sky temperature measurement
2017-10-14 Implement handling for external sensors
2017-10-26 Fix binary logic when manipulating relay open / fuse triggered fields
    [USB.cpp]
2017-10-26 initialize output to default settings when calibrating
2017-10-26 fix serial number endianness
    [status.py]
2017-10-27 Turn output off at the end of a calibration run
2017-11-09 Disable UI updates when data is updated from the device
2018-05-08 Fix boot loader entry
    [USB.cpp]
2018-05-08 Scale temperature values properly
2018-07-30 Add support for board version specific functionality. Make power measurement divisor different for 1.0 / 1.1 boards.
2018-07-30 Verify that the output can turn itself off at the end of calibration run
2018-09-22 Add STL files for case
    [Komahub-1.2-BODY.stl, Komahub-1.2-LID.stl, Komahub-1.2-LOGO.stl]
2018-09-30 Add connector documentation image
2018-10-25 Better error handling to device detection
2018-10-31 Add schematics for board rev 1.2
    [komahub-v1.2.brd, komahub-v1.2.sch]
2018-10-31 Get rid of feature flags and actually detect sensors; add sensor present data to status output
2018-10-31 Fix AUX1 pin assignment
    [KomaHubPins.h]
2018-11-03 Support MLX90614 sensor for sensing sky temperature
2018-11-03 Read and display sensor data
2018-11-03 Display dew point and second external temperature in control application
2018-11-03 Add /sensors query to REST api
2018-11-03 Describe sensor usage in the manual
2018-11-05 äElaborate sensor descriptions on required pull-up resistors
2018-11-06 ASCOM ObservingConditions driver

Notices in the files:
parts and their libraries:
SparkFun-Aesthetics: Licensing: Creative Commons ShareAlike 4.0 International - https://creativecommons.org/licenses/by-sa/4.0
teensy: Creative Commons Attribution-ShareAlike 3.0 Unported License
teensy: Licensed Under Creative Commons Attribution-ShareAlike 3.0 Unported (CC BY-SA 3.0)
